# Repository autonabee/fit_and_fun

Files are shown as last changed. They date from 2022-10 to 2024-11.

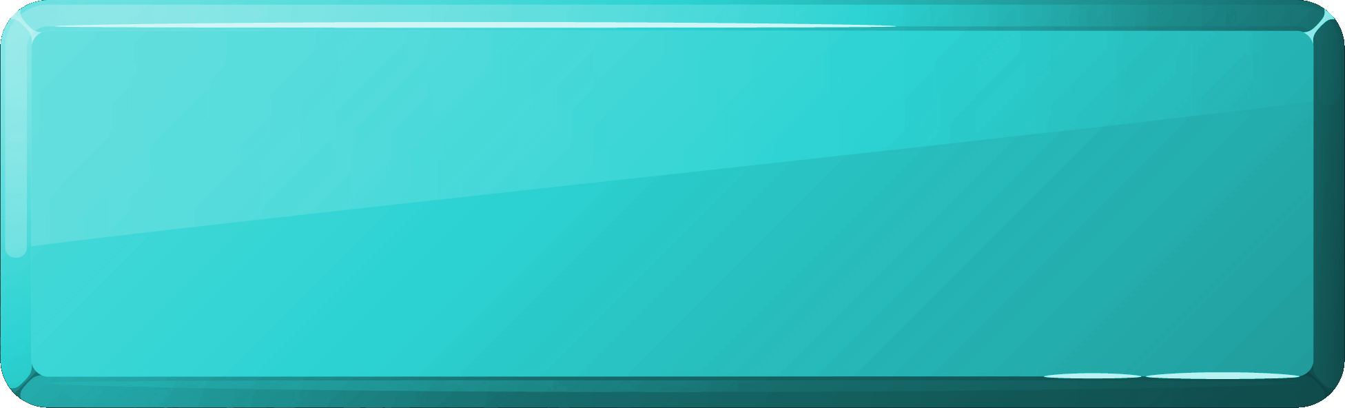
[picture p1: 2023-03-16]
games/whattheduck/images/button_blue.png

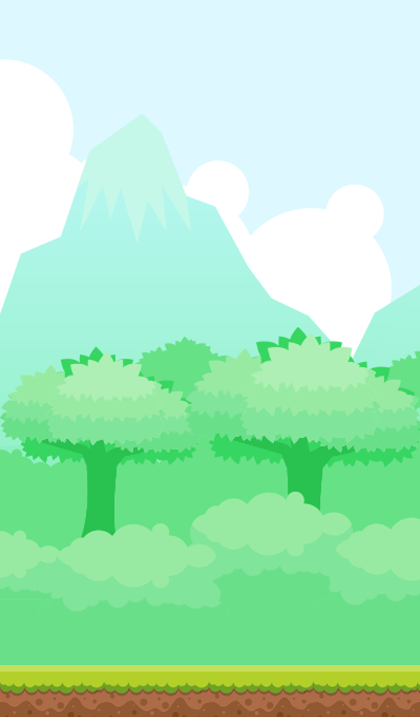
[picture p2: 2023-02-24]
games/whattheduck/images/menu_bg_portrait.png

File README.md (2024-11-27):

# fit_and_fun

An interactive device to make a hand pedal fun

# Contributors
Coders : Roger, Simeon, Clémentine, Rémi, Astrale, Cécile
NGOs : AutonaBee, MyHumanKit, Humanlab Saint-Pierre

# Material
## Harware
- Raspberry (tested version : 4 Model B - OS Rasbian)
- ESP 32
- LCD 9 pouces, 1024x600, 43 euros : <https://fr.aliexpress.com/item/32954126627.html>
(User manual : <https://usermanual.wiki/Pdf/ERVB800168Datasheet.1273732525/html>)

## CAD file
To be uploaded

## Homemade Electronic
To be uploaded

# Start the program
## Options d'exécution

* `-b [host_ip]` : Spécifie l'adresse du broker MQTT (localhost par défaut)
* `-d` : Active le mode debug qui affiche des infos supplémentaires dans la console
* `-f` : Affiche le jeu en mode plein écran ; déconseillé sur un appareil dont la résolution n'est pas 1024x600
* `-l` : Ne se connecte pas au broker MQTT
* `-o [portrait|landscape]` : Lance le jeu en portrait ou en paysage (portrait par défaut)
  
## On the AutonaBee's setup - WORKING DEMO
To be documented

## On Raspberry 
__Attention__ : Avant de lancer le programme pour la première fois, exécuter :
```
python reset_database.py
```

Avec le raspberry en wifi access-point (ssid:fit_and_fun) et un écran classique sur la raspberry. Après configuration Wifi/Mqtt coté raspberry (`sudo systemctl restart mosquitto`) et mis sous tension le capteur ESP2866+BNO05, on peut lancer le jeu: `python fit_and_fun.py -f`.
Quand le capteur tourne sur lui-même (axe Z), la rivière avance et si on passe une certaine vitesse, le personnage avance aussi. Le score augmente en fonction de la durée/vitesse et si le personnage touche les obstacles  qui traverse la rivière.

## On another system
__Attention__ : Avant de lancer le programme pour la première fois, exécuter :
```
python reset_database.py
```

Avec le raspberry allumé en wifi access-point (ssid:fit_and_fun), et un capteur (ESP+BN0 ou M5Stick) :
Connecter l'appareil au réseau Wi-Fi `fit_and_fun` et lancer le programme : `python fit_and_fun.py -b 10.42.0.1`

# Files description

* `console.py`: Entry menu of the game before launching the Canoe game
* `game_canoe.py`: Canoe game (GameCanoe inherit from Console)
* `game_entities.py`: pygame elements for Canoe game
* `fit_and_fun_keyboard.py`: main to launch the game with keyboard interaction (without mqtt)
* `mqtt_subscriber.py`: mqtt subscriber to read the topic `fit_and_fun/speed`
* `sensor_keyboard.py`: main to control the game in the other part with keyboard interaction (with mqtt)
* `fit_and_fun.py`: main to launch the game controllable through mqtt (topic `fit_and_fun/speed`)
* `reset_database.py` : python script which resets the database stored as `fit_and_fun.db`
* `sensors/FAF_ESP/FAF_ESP.ino`: firmware for the gyro sensor (ESP2866+BNO05) sending rot speed through mqtt
* `sensors/FAF_STICK5/FAF_STICK5.ino`: firmware for the gyro sensor (M5StickC-P), sending rot speed through mqtt to be tested.

# First Installation

## Install first librairies
- Python 3.9 - Main code
- Mosquitto (sudo apt install -y mosquitto  mosquitto-clients) - Libraity to interface MQTT broker
- Pygame (pip install -y pygame pygame-menu paho-mqtt readchar) - Librairy for the game graphic design and dynamics

## Configure the MQTT broker
Add at this end of the file: `/etc/mosquitto/mosquitto.conf`
```
listener 1883 localhost 
listener 1883 10.42.0.1
allow_anonymous true
```

- Restart the service everytime the rasberri pi was disconnected from fit_and_fun
```
sudo systemctl restart mosquitto
```
Some tips to debug
* see the log: `sudo tail -f /var/log/mosquitto/mosquitto.log`
* connection to the socket port: `nc -z -v -u 10.42.0.1 1883`
* connection to the topic through the broker:`mosquitto_sub -h 10.42.0.1 -t "fit_and_fun/speed"`
* publish a topic: `mosquitto_pub -h 10.42.0.1 -t "fit_and_fun/speed" -mode "10.0"`

## Configure Wifi access point

* Follow instruction from : <https://www.tomshardware.com/how-to/raspberry-pi-access-point>
* At the step "Setting up the Access Point on Raspberry Pi", give the name to the network : `fit_and_fun` and  select the mode "No security"
* Check automatic connection of the Raspberry to network "fit_and_fun", and that the static IP is 10.42.0.1

## Configure screen parameters
* Add in ```/boot/config.txt```
```
hdmi_group=2
hdmi_mode=87
hdmi_cvt=1024 600 60 6 0 0 0
hdmi_drive=1
```

* Modify file  ```/boot/cmdline.txt```
```
[...] video=HDMI-A-1:1024x600M@60,margin_left=0,margin_right=0,margin_top=0,margin_bottom=0
```
__Attention__ : add on the same line as the other instructions
__Attention__ : add a space in between

## Start Python main program for the first time - TO BE TESTED
* Modification de ```/etc/xdg/lxsession/LXDE-pi/autostart```, ajouter :
```
@lxterminal
```

* Connaître l'identifiant de l'écran, exécuter la commande
```xinput```
et copier le résultat qui correspond à l'appareil utilisé. Par exemple, avec l'écran WaveShare conseillé, l'identifiant correspondant est `WaveShare WS170120`

* Ajouter dans le .bashrc :
```
DISPLAY=:0 xrandr --output HDMI-1 --rotate left
xinput set-prop '[screen_id]' 'Coordinate Transformation Matrix' 0 -1 1 1 0 0 0 0 1
systemctl start mosquitto
cd [your_path]/fit_and_fun
python fit_and_fun.py -f
```
## Configure the Hardware
TO BE UPDATED FROM ARCHIVE

# Problems to solve

- Wifi Access point
La connexion Wi-Fi fonctionne si le hotspot partagé ne possède pas de sécurité (WEP, WPA2, etc.)
Aucune des deux cartes (M5Stick ou ESP32) ne parvient à se connecter si le hotspot est sécurisé. Il s'agit probablement d'un problème au niveau de la bibliothèque "WiFi.h" d'Arduino ou bien de la manière dont le réseau est partagé depuis le Raspberry. Pas d'info utile trouvée sur Internet ; à chercher...

# Liens utiles

* Pygame
 
  * <https://pythonfaqfr.readthedocs.io/en/latest/pygame_collisions.html>

* M5stackC-Plus
  * <https://docs.m5stack.com/en/core/m5stickc_plus>
  * <https://github.com/m5stack/M5StickC-Plus>
  * <https://community.m5stack.com>
  * <https://www.hackster.io/m5stack>
* MQTT
  * <https://randomnerdtutorials.com/esp32-mqtt-publish-subscribe-arduino-ide>
  * <https://diyi0t.com/introduction-into-mqtt>
  * <https://learn.sparkfun.com/tutorials/introduction-to-mqtt>
  * <https://medium.com/python-point/mqtt-basics-with-python-examples-7c758e605d4>
  * <https://www.tutos.eu/4910>
* Config Ecran
  * <https://www.raspberrypi.com/documentation/computers/config_txt.html>
* Wifi access point
  * <https://www.tomshardware.com/how-to/raspberry-pi-access-point>

# Licenses

* Le logiciel est sous licence [Cecill](./COPYING)
* Les boitiers sont sous licence [Creative-Common](cad/COPYING.md)

----------------------------------------------------------------------------------------
# Archive
Première version avec un capteur MStick5C-P qui envoie la vitesse de rotation du capteur par MQTT/wifi à un jeu pygame
sur PC.

### M5Stick-C P

* Capteur inertiel : M5stickC-Plus : <https://www.gotronic.fr/art-module-m5stickc-plus-k016-p-33740.htm>
* Config Arduino: <https://docs.m5stack.com/en/quick_start/m5stickc_plus/arduino> pour installation libs et plateforme.
* lib mqtt: <https://www.arduino.cc/reference/en/libraries/pubsubclient>
* Programmer (configurer access wifi et IP broker): `FAF_STICK5/FAF_STICK5.ino`

### ESP2866+BNO05

* micro-controleur ESP2866 avec une IMU BNO05 via I2C
* <https://learn.adafruit.com/adafruit-bno055-absolute-orientation-sensor>
* lib mqtt: <lib https://www.arduino.cc/reference/en/libraries/pubsubclient>
* Programmer (configurer access wifi et IP broker): `FAF_ESP/FAF_ESP.ino`

## Pour ajouter un jeu

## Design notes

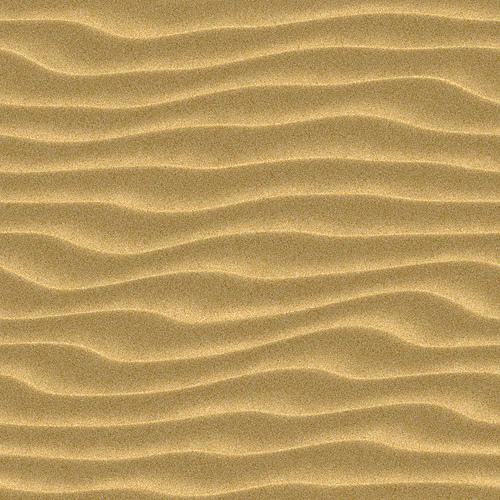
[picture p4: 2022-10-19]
games/whattheduck/images/desert.jpg

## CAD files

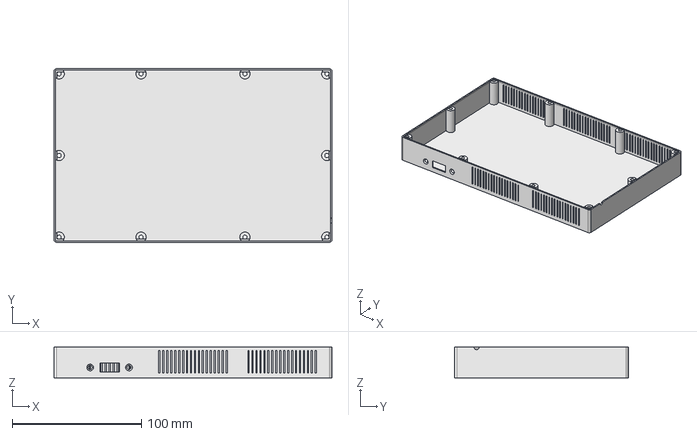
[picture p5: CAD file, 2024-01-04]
cad/back.FCStd
215.0 x 134.3 x 23.7 mm

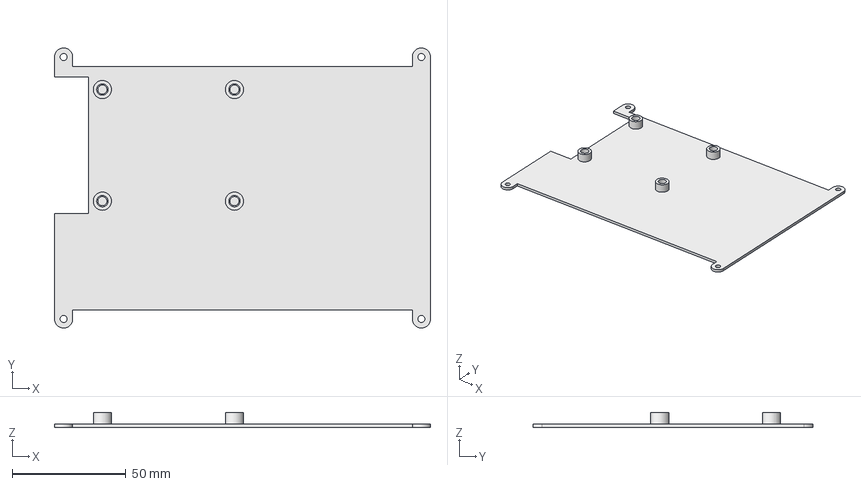
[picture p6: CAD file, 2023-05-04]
cad/middle.FCStd
165.1 x 123.0 x 6.60 mm

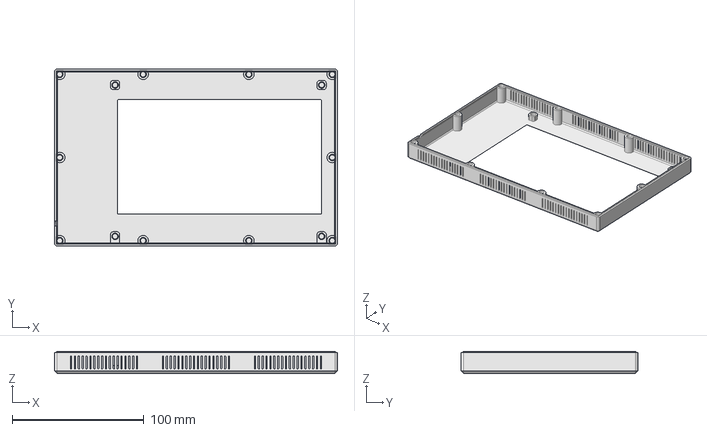
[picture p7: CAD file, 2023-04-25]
cad/front.FCStd
215.0 x 134.3 x 16.8 mm

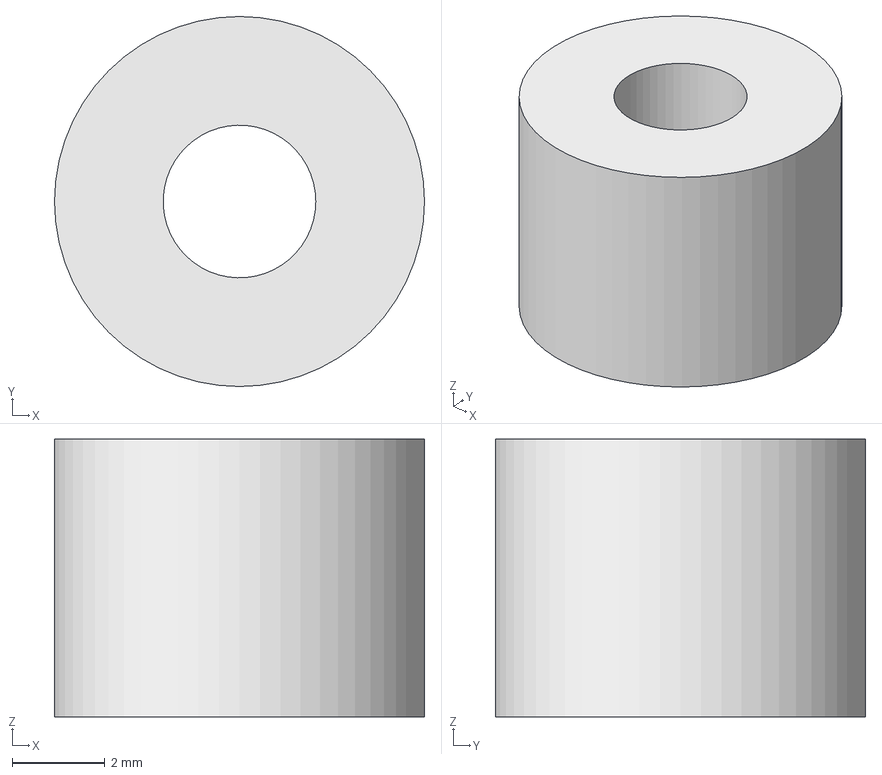
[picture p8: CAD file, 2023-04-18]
cad/spacer.FCStd
8.00 x 8.00 x 6.00 mm

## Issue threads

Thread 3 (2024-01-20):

Gameplay, absence de canards dans la zone central

ReneGaussier, 2024-01-20:
Lors des phase de jeu, peu import la phase ou le niveau aucun canards n'apparais dans la zone central de l'écran.
l'apparition des obstacles en plein devrais ajouter une diversité de gameplay

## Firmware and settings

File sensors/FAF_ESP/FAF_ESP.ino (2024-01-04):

/*
* This file is a part of Fit and Fun
*
* Copyright (C) 2023 Inria/Autonabee
*
* This software is governed by the CeCILL license under French law and
* abiding by the rules of distribution of free software.  You can  use, 
* modify and/ or redistribute the software under the terms of the CeCILL
* license as circulated by CEA, CNRS and INRIA at the following URL
* "http://www.cecill.info". 
*
* As a counterpart to the access to the source code and  rights to copy,
* modify and redistribute granted by the license, users are provided only
* with a limited warranty  and the software's author,  the holder of the
* economic rights,  and the successive licensors  have only  limited
* liability.
*/

#include <WiFi.h>
#include <PubSubClient.h>
#include <Adafruit_Sensor.h>                                                    
#include <Adafruit_BNO055.h>   

WiFiClient espClient;
PubSubClient client(espClient);

const char* ssid        = "fit_and_fun";
const char* password    = "fun_and_fit";
const char* mqtt_server = "10.42.0.1";

const int buttonSelectPin = 14;
const int buttonDownPin = 15;
int buttonSelectState = 0;
int buttonDownState = 0;

const int ledPin =  13;      // the number of the LED pin

#define MSG_BUFFER_SIZE (10)
char msg[MSG_BUFFER_SIZE];
float value = 51.0;

/* Set the delay between fresh samples */                                       
uint16_t BNO055_SAMPLERATE_DELAY_MS = 100;                                      
/* Check I2C device address */                                                          
Adafruit_BNO055 bno = Adafruit_BNO055(55, 0x28); 


void setupWifi();
void reConnect();

void setupWifi() {
    delay(10);
    Serial.print("Connecting to ");
    Serial.println(ssid);
    //WiFi.begin(ssid, password);  // Start Wifi connection.
    WiFi.begin(ssid);

    while (WiFi.status() != WL_CONNECTED) {
        delay(500);
        Serial.print(".");
    }
    Serial.println("Connected to the WiFi network");
    Serial.print("Local ESP32 IP: ");
    Serial.println(WiFi.localIP());
}

void setup() {
  // put your setup code here, to run once:
  Serial.begin(115200); 
  setupWifi(); 
  client.setServer(mqtt_server, 1883); 
  
  /* Initialise the sensor */                                                   
  if (!bno.begin())                                                             
  {                                                                             
    /* There was a problem detecting the BNO055 ... check your connections */   
    Serial.print("Ooops, no BNO055 detected ... Check your wiring or I2C ADDR!"\
);                                                                              
    while (1);                                                                  
  }       

  pinMode(buttonSelectPin, INPUT_PULLUP);
  pinMode(buttonDownPin, INPUT_PULLUP);
  pinMode(ledPin, OUTPUT);
  
  delay(1000);                                                                                   
                  
}

void loop() {
  if (!client.connected()) {
        reConnect();
    }
  client.loop(); 
  
  /* Get a new sensor event */
  sensors_event_t event;
  bno.getEvent(&event, Adafruit_BNO055::VECTOR_GYROSCOPE);
  Serial.print(F("Gyro: "));
  Serial.print((float)event.gyro.x);
  Serial.print(F(" "));
  Serial.print((float)event.gyro.y);
  Serial.print(F(" "));
  Serial.print((float)event.gyro.z);
  Serial.println(F(""));

  /* Creation and sending of a speed message */
  snprintf(msg, MSG_BUFFER_SIZE, "%6.2f", (float)event.gyro.z);
  client.publish("fit_and_fun/speed", msg);
  Serial.print("mqtt publish speed: ");
  Serial.println(msg);

  /* Creation and sending of a select button message */
  buttonSelectState = digitalRead(buttonSelectPin);
  snprintf(msg, MSG_BUFFER_SIZE, "%s", buttonSelectState == HIGH ? "false" : "true");
  client.publish("fit_and_fun/select", msg);
  Serial.print("mqtt publish select: ");
  Serial.println(msg);
  
  /* Creation and sending of a down button message */
  buttonDownState = digitalRead(buttonDownPin);  
  snprintf(msg, MSG_BUFFER_SIZE, "%s", buttonDownState == HIGH ? "false" : "true");
  client.publish("fit_and_fun/down", msg);
  Serial.print("mqtt publish down: ");
  Serial.println(msg);
  
  delay(BNO055_SAMPLERATE_DELAY_MS);
}

void reConnect() {
    while (!client.connected()) {
        Serial.print("Attempting MQTT connection...");
        // Create a random client ID.  
        String clientId = "M5Stack-";
        clientId += String(random(0xffff), HEX);
        // Attempt to connect. 
        if (client.connect(clientId.c_str())) {
            Serial.println("\nSuccess\n");
            // Once connected, publish an announcement to the topic.
            client.publish("fit_and_fun", "M5Stack init");
            // ... and resubscribe.
            client.subscribe("fit_and_fun");
        } else {
            Serial.print("failed, rc=");
            Serial.print(client.state());
            Serial.println("try again in 5 seconds");
            delay(5000);
        }
    }
}

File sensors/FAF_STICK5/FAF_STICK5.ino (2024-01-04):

/*
* This file is a part of Fit and Fun
*
* Copyright (C) 2023 Inria/Autonabee
*
* This software is governed by the CeCILL license under French law and
* abiding by the rules of distribution of free software.  You can  use, 
* modify and/ or redistribute the software under the terms of the CeCILL
* license as circulated by CEA, CNRS and INRIA at the following URL
* "http://www.cecill.info". 
*
* As a counterpart to the access to the source code and  rights to copy,
* modify and redistribute granted by the license, users are provided only
* with a limited warranty  and the software's author,  the holder of the
* economic rights,  and the successive licensors  have only  limited
* liability.
*/

/*
* Inspired by M5StickC-Plus sample source code
* Visit for more information: https://docs.m5stack.com/en/core/m5stickc_plus
*/


#include "M5StickCPlus.h"
#include <WiFi.h>
#include <PubSubClient.h>

WiFiClient espClient;
PubSubClient client(espClient);

// Configure the name and password of the connected wifi and your MQTT Serve
// host. 
const char* ssid        = "fit_and_fun";
const char* password    = "fun_and_fit";
const char* mqtt_server = "10.42.0.1";

unsigned long lastMsg = 0;
#define MSG_BUFFER_SIZE (50)
char msg[MSG_BUFFER_SIZE];
int value = 0;

float gyroX = 0.0F;
float gyroY = 0.0F;
float gyroZ = 0.0F;


void setupWifi();
void callback(char* topic, byte* payload, unsigned int length);
void reConnect();

void setup() {
    M5.begin();
    M5.Lcd.setRotation(3);
    setupWifi();
    M5.Imu.Init();          // Init IMU.  
    client.setServer(mqtt_server,
                     1883);  // Sets the server details.  
    client.setCallback(
        callback);  // Sets the message callback function.
}

void loop() {
    if (!client.connected()) {
        reConnect();
    }
    client.loop();  // This function is called periodically to allow clients to
                    // process incoming messages and maintain connections to the
                    // server.
    M5.IMU.getGyroData(&gyroX, &gyroY, &gyroZ);
    //M5.Lcd.printf("GYRO: %6.2f  %6.2f  %6.2f\n", gyroX, gyroY, gyroZ);
    //snprintf(msg, MSG_BUFFER_SIZE, "%6.2f", (gyroZ+12)*15/600);
    snprintf(msg, MSG_BUFFER_SIZE, "%6.2f", (gyroZ / 360) * 2*PI);
    Serial.println((gyroZ / 360) * 2*PI);
    client.publish("fit_and_fun/speed", msg);
    
    delay(500);
    
/*
    unsigned long now =
        millis();  // Obtain the host startup duration.
    if (now - lastMsg > 2000) {
        lastMsg = now;
        ++value;
        M5.Lcd.printf("GYRO: %6.2f  %6.2f  %6.2f\n", gyroX, gyroY, gyroZ);
        snprintf(msg, MSG_BUFFER_SIZE, "%6.2f",
                 gyroX);  // Format to the specified string and store it in MSG.
        M5.Lcd.print("Publish message: ");
        M5.Lcd.println(msg);
        client.publish("fit_and_fun/speed", msg);  // Publishes a message to the specified
                                         // topic.
        if (value % 7 == 0) {
            M5.Lcd.fillScreen(BLACK);
            M5.Lcd.setCursor(0, 0);
        }
    }
    */
    
}


void setupWifi() {
    delay(10);
    M5.Lcd.printf("Connecting to %s", ssid);
    WiFi.mode(WIFI_STA);  // Set the mode to WiFi station mode.  
    WiFi.begin(ssid);  // Start Wifi connection.

    while (WiFi.status() != WL_CONNECTED) {
        delay(500);
        M5.Lcd.print(".");
    }
    M5.Lcd.print("\nConnected to the WiFi network");
    M5.Lcd.print("Local ESP32 IP: ");
    M5.Lcd.println(WiFi.localIP());
}


void callback(char* topic, byte* payload, unsigned int length) {
    M5.Lcd.print("Message arrived [");
    M5.Lcd.print(topic);
    M5.Lcd.print("] ");
    for (int i = 0; i < length; i++) {
        M5.Lcd.print((char)payload[i]);
    }
    M5.Lcd.println();
}


void reConnect() {
    while (!client.connected()) {
        M5.Lcd.print("Attempting MQTT connection...");
        // Create a random client ID.  
        String clientId = "M5Stack-";
        clientId += String(random(0xffff), HEX);
        // Attempt to connect. 
        if (client.connect(clientId.c_str())) {
            M5.Lcd.printf("\nSuccess\n");
            // Once connected, publish an announcement to the topic.
            client.publish("fit_and_fun", "M5Stack init");
            // ... and resubscribe.
            client.subscribe("fit_and_fun");
        } else {
            M5.Lcd.print("failed, rc=");
            M5.Lcd.print(client.state());
            M5.Lcd.println("try again in 5 seconds");
            delay(5000);
        }
    }
}

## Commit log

2022-10-18 add mqtt sensor esp2866+BNO05
2022-10-20 décors sur les rives
2023-02-13 Ignore arduino generated files
2023-02-14 Attempts to connect buttons with MQTT
2023-02-14 Implements buttons connection with MQTT (based on commit 625115)
2023-02-15 Simulate inputs for both buttons (for navigation in menus)
2023-02-21 Add a timer and fix intro scroll speed
2023-02-22 Change the way buttons are used inside the code
2023-03-07 Fix stage removal
2023-03-07 Add 'add stage' button
2023-03-09 Upgrade stages design and back-end functioning
2023-03-09 Add 'local' storage of stages values
2023-03-10 Optimize stage removal
2023-03-16 Add button skins and improve select_user_ui layout
2023-03-17 Apply visual changes to exercise selection (dropselect clipping with buttons)
2023-03-22 Apply exercise's parameters to the game (for now, resistance increases event spawn rate)
2023-04-18 Add CAD files of the packaging
    [back.FCStd, front.FCStd, middle.FCStd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]
2023-04-19 Add loading image when charging exercise planning
2023-04-25 Edit front CAD for a better screen alignement
    [front.FCStd]
2023-04-26 Add loading image when adding new stage to an exercise
2023-05-04 Edit back and middle CADs to include USB support
    [back.FCStd, middle.FCStd]
2023-05-05 Fix alimentation alignement in back CAD
    [back.FCStd]
2023-05-16 Fix issue : program crash when deleting a stage in exercise planning
2023-05-23 Fix inserts alignement in back CAD
    [back.FCStd]
2023-10-08 suppress warning about set_font button
2024-11-16 ajout print
2024-11-16 add missing vitesse to Stage SQL table
